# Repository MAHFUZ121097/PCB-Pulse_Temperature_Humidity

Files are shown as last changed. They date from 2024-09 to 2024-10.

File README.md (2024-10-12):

# Pulse Oximeter and Temperature-Humidity Sensor PCB

## Overview

This repository contains the design and firmware for a custom Printed Circuit Board (PCB) that integrates both a pulse oximeter and a temperature-humidity sensor. This PCB is designed to monitor vital physiological data, making it suitable for health monitoring and IoT applications.

### PCB Image
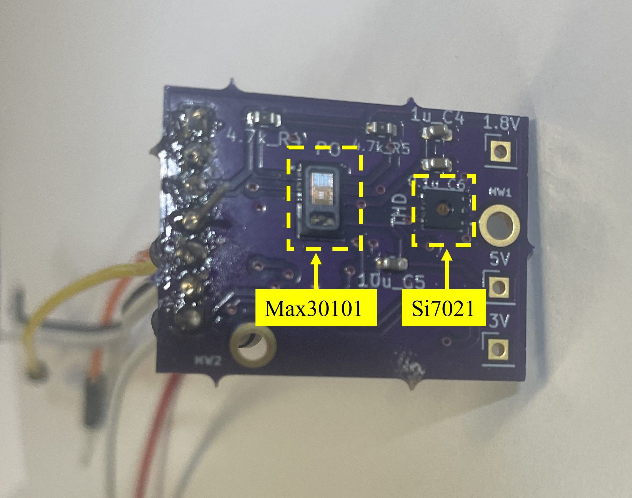
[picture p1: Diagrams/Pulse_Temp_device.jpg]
PCB Design


### Key Components:
- **Pulse Oximeter IC**: MAX30101
- **Temperature-Humidity IC**: Si7021
- **Voltage Regulators**: 5V, 1.8V

The PCB design ensures efficient power regulation and integrates sensor functionality in a compact, easy-to-use form.

## Components Description

### Pulse Oximeter (MAX30101)
- The MAX30101 is an integrated pulse oximetry and heart-rate monitor IC. It uses two LEDs (red and infrared) and a photodetector to measure blood oxygen saturation and heart rate.

### Temperature-Humidity Sensor (Si7021)
- The Si7021 is a digital temperature and humidity sensor with high accuracy and low power consumption. It provides environmental data that can be used to monitor air quality or adjust for environmental conditions in health monitoring applications.

### Voltage Regulators
- The PCB includes voltage regulation circuits for powering the sensors and components:
  - **5V Regulator**: For high logic level for MAX30101 operation
  - **1.8V Regulator**: For low logic level for MAX30101 operation

## Features
- **Compact design** that integrates both sensors on a single PCB.
- **Accurate physiological monitoring** using the MAX30100 pulse oximeter and the Si7021 temperature-humidity sensor.
- **Efficient power management** with onboard voltage regulators (5V and 1.8V).

## PCB Specifications
- **Design environment**: KiCad EDA 6.0.10
- **Dimensions**: 30 mm X 22 mm
- **Operating Voltage**: ~ 3V.
- **Interfaces**: I2C communication pins for data exchange between the sensors and microcontroller.

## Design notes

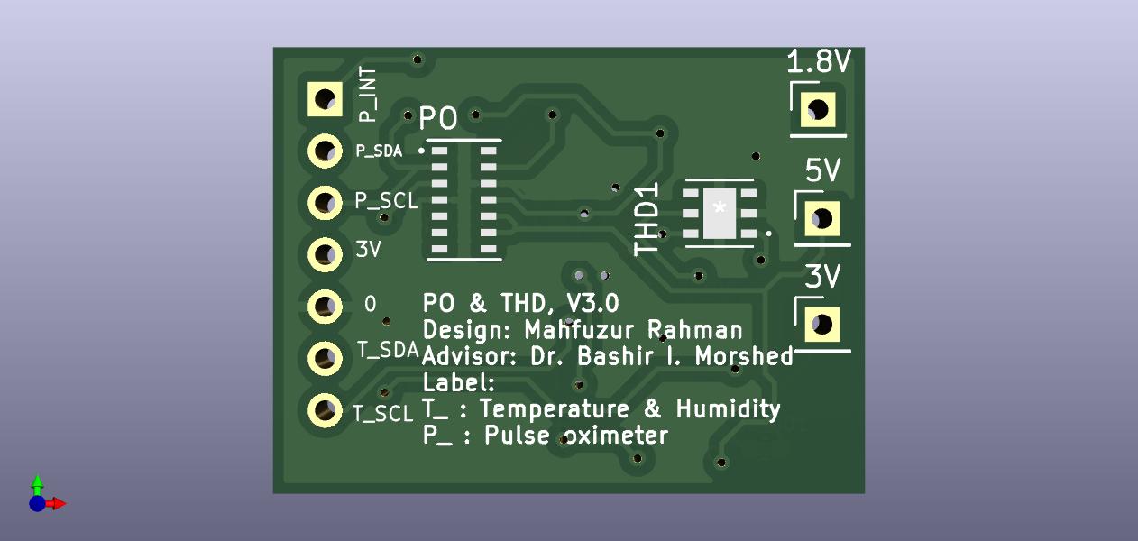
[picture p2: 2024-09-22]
Diagrams/Pulse_Temp_Top.jpg

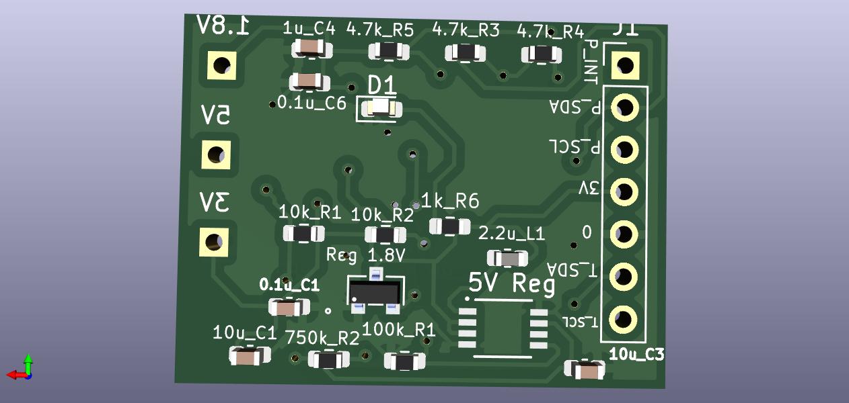
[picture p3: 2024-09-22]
Diagrams/Pulse_Temp_bottom.jpg

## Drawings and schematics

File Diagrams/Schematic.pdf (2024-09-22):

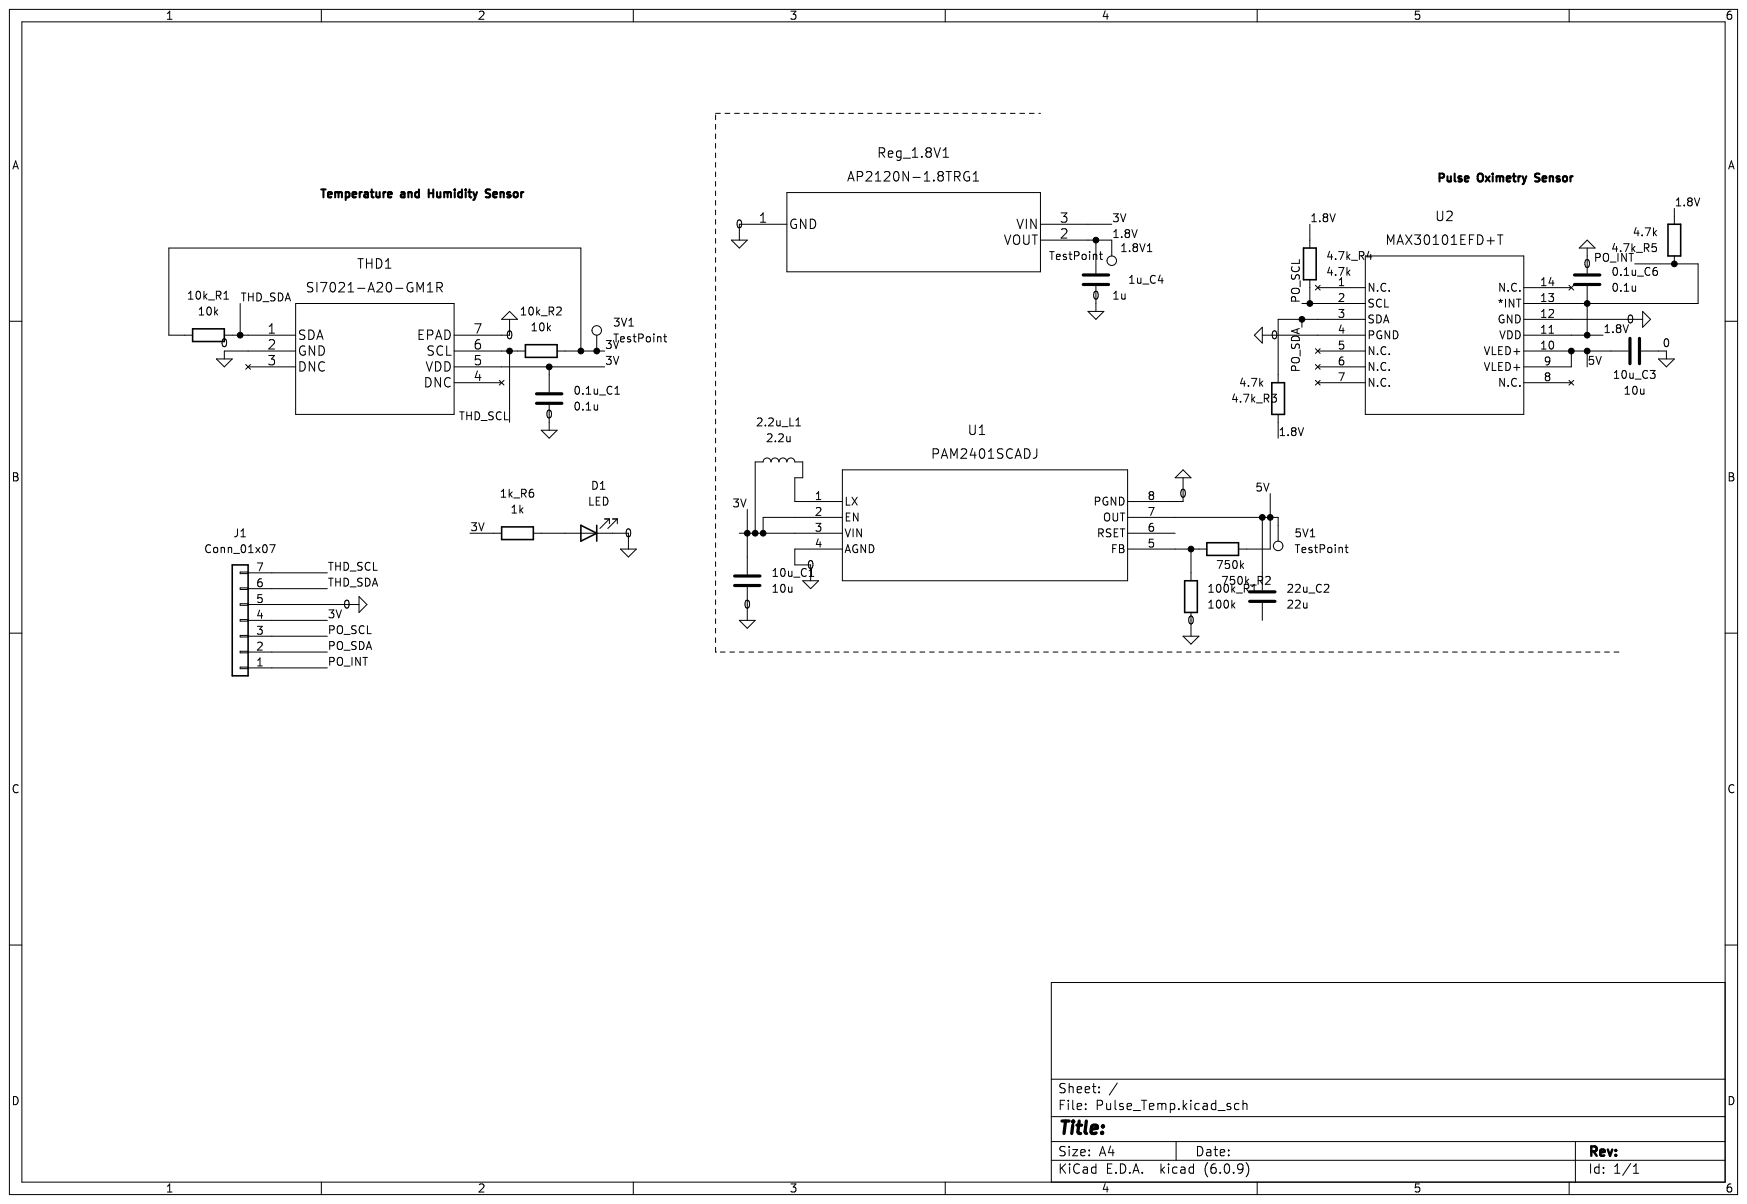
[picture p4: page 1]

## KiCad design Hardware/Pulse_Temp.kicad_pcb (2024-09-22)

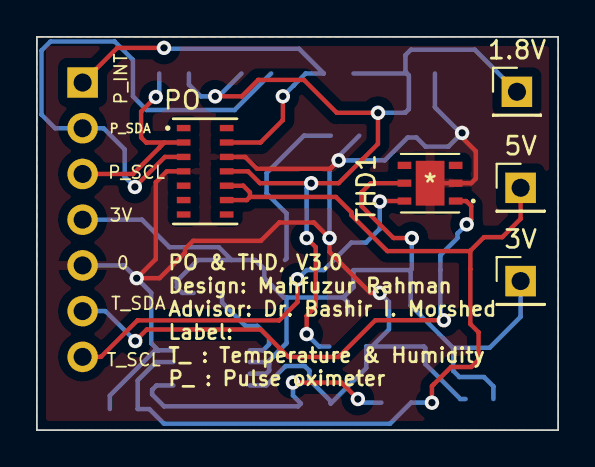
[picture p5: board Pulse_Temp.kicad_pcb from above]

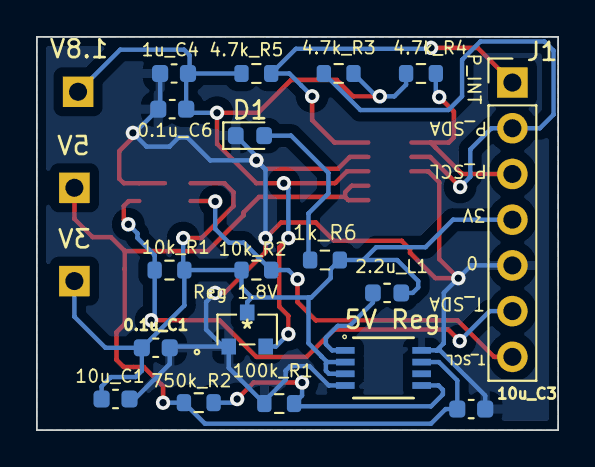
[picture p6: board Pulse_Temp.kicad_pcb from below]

Board: 2 copper layers, 29.0 x 21.8 mm, 23 parts (18 on the bottom side), 12 nets.

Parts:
0.1u_C1, 0.1u_C6: 0.1u; C_0603_1608Metric
1.8V, 3V, 5V: TestPoint; PinHeader_1x01_P2.54mm_Vertical
1k_R6: 1k; R_0603_1608Metric
1u_C4: 1u; C_0603_1608Metric
2.2u_L1: 2.2u; L_0603_1608Metric
4.7k_R3, 4.7k_R4, 4.7k_R5: 4.7k; R_0603_1608Metric
5V Reg: PAM2401SCADJ; MSOP8_DIO
10k_R1, 10k_R2: 10k; R_0603_1608Metric
10u_C1, 10u_C3: 10u; C_0603_1608Metric
100k_R1: 100k; R_0603_1608Metric
750k_R2: 750k; R_0603_1608Metric
D1: LED; LED_0603_1608Metric
J1: Conn_01x07; PinHeader_1x07_P2.54mm_Vertical
PO: MAX30101EFD+T; 21-1048F_F143A5&plus_1_MXM
Reg 1.8V: AP2120N-1.8TRG1
THD1: SI7021-A20-GM1R

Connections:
0: 0.1u_C1.2, 0.1u_C6.1, 1u_C4.2, 5V Reg.4 (AGND), 5V Reg.8 (PGND), 10u_C1.2, 10u_C3.2, 100k_R1.2, D1.1 (K), J1.5, PO.4 (PGND), PO.12 (GND), Reg 1.8V.1 (GND), THD1.2 (GND), THD1.7 (EPAD)
/1.8V: 0.1u_C6.2, 1.8V.1, 1u_C4.1, 4.7k_R3.2, 4.7k_R4.1, 4.7k_R5.2, PO.11 (VDD), Reg 1.8V.2 (VOUT)
/3V: 0.1u_C1.1, 1k_R6.1, 2.2u_L1.1, 3V.1, 5V Reg.2 (EN), 5V Reg.3 (VIN), 10k_R1.1, 10k_R2.2, 10u_C1.1, J1.4, Reg 1.8V.3 (VIN), THD1.5 (VDD)
/5V: 5V.1, 5V Reg.7 (OUT), 10u_C3.1, 750k_R2.2, PO.9 (VLED+), PO.10 (VLED+)
/PO_INT: 4.7k_R5.1, J1.1, PO.13 (*INT)
/PO_SCL: 4.7k_R4.2, J1.3, PO.2 (SCL)
/PO_SDA: 4.7k_R3.1, J1.2, PO.3 (SDA)
/THD_SCL: 10k_R2.1, J1.7, THD1.6 (SCL)
/THD_SDA: 10k_R1.2, J1.6, THD1.1 (SDA)
unnamed: 1k_R6.2, D1.2 (A)
unnamed: 2.2u_L1.2, 5V Reg.1 (LX)
unnamed: 5V Reg.5 (FB), 100k_R1.1, 750k_R2.1

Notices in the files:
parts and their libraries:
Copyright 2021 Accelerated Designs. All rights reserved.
